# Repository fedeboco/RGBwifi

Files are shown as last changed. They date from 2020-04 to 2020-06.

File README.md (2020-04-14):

# ESP 8266 Wi-Fi RGB LED Strip Controller

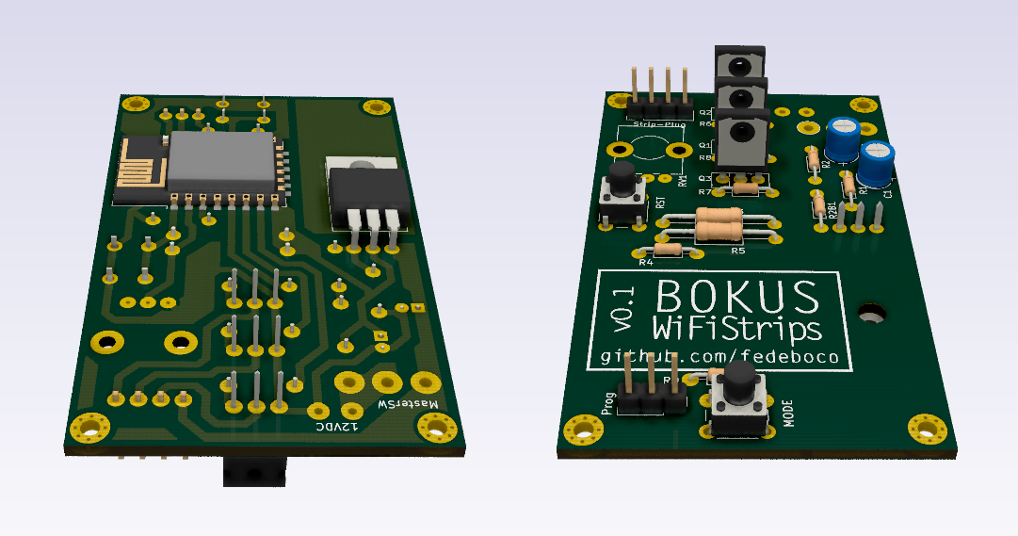
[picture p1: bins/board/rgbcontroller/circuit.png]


### Idea
- Local network WiFi server.
- Browser GUI for color selection.
- Analog on-board hue-color and brightness selection.
- Multiple board control (not implemented yet).

### WiFi Configuration Example

Connecting to an specific Wi-Fi network will be possible by fisrt connecting to an Access Point created by the ESP and sending the credentials using that network. The device stores the settings in EEPROM and restarts with the desired network configured.

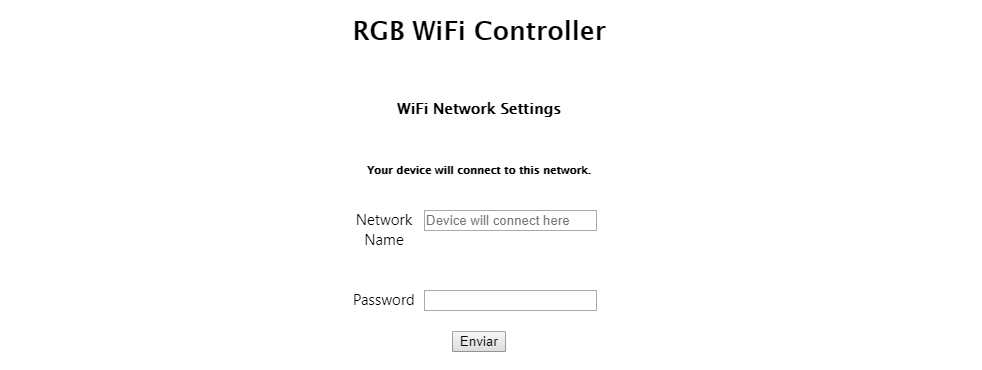
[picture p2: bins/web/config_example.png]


### Use Example

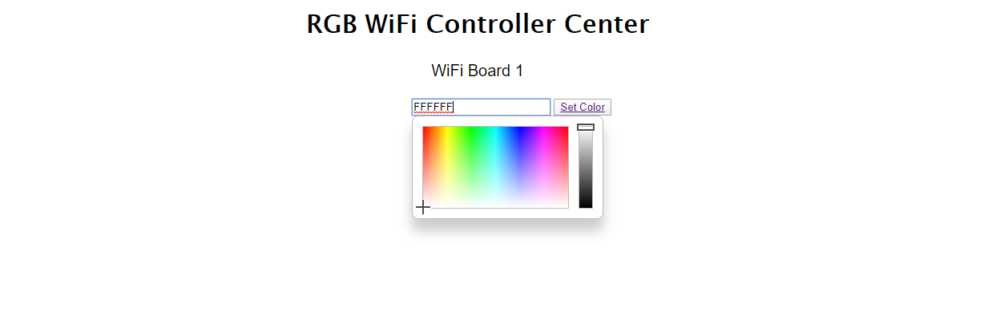
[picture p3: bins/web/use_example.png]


### Software and Dependencies
- Arduino IDE 1.8.3
- ESP8266 Board Driver by EP8266 Community. v2.5.0. https://github.com/esp8266/Arduino
- ESP8266 Web Server v1.0.0
- JavaScript Color Picker http://jscolor.com/

### Schematic

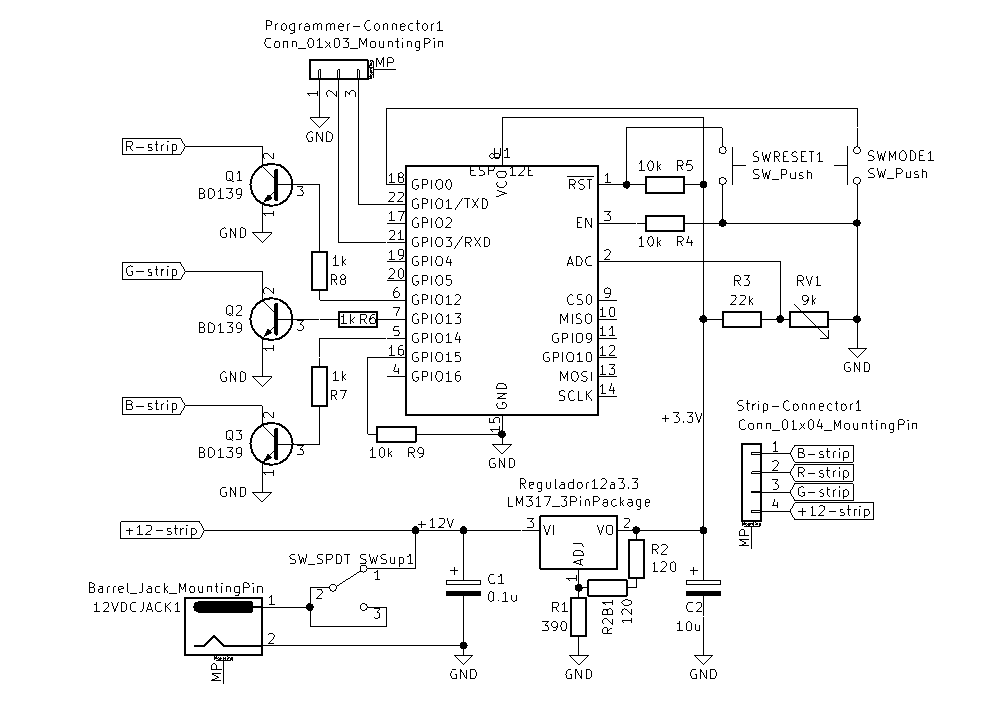
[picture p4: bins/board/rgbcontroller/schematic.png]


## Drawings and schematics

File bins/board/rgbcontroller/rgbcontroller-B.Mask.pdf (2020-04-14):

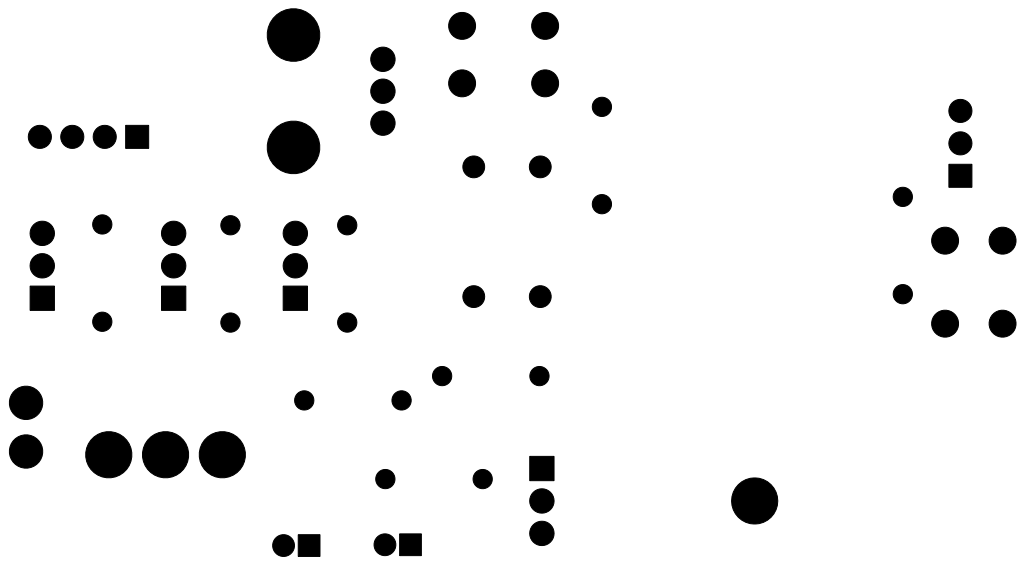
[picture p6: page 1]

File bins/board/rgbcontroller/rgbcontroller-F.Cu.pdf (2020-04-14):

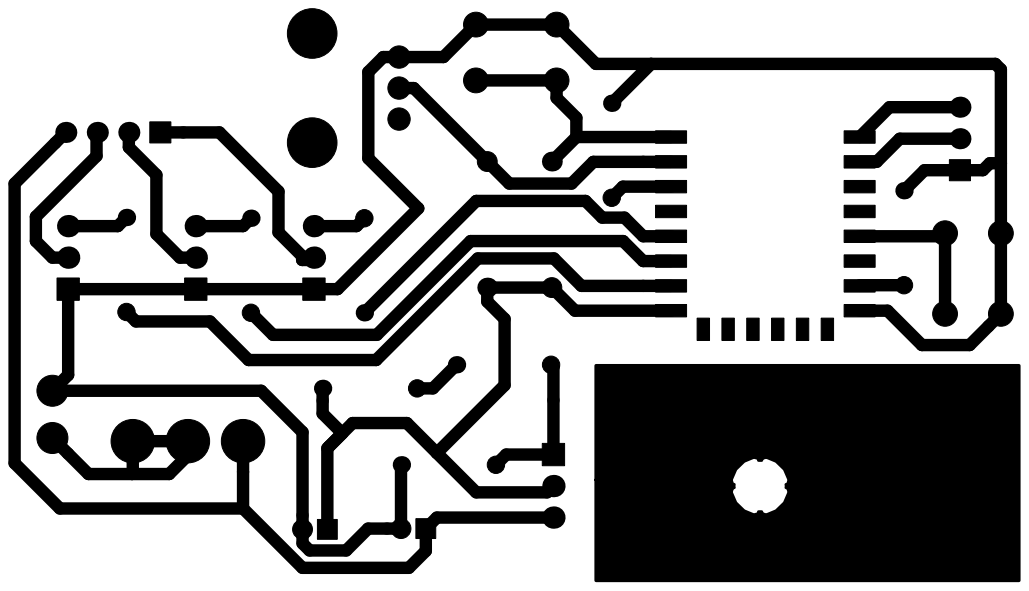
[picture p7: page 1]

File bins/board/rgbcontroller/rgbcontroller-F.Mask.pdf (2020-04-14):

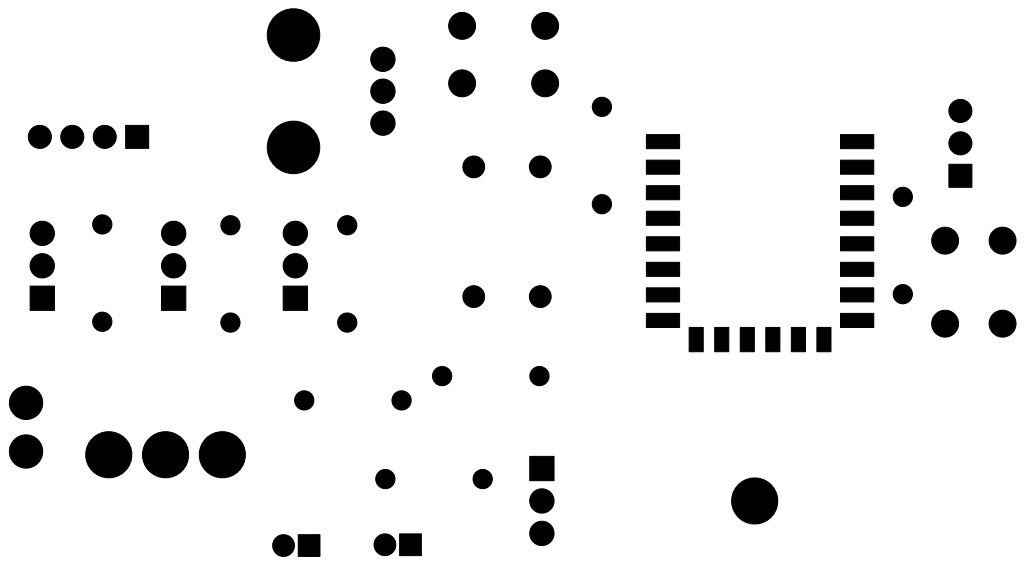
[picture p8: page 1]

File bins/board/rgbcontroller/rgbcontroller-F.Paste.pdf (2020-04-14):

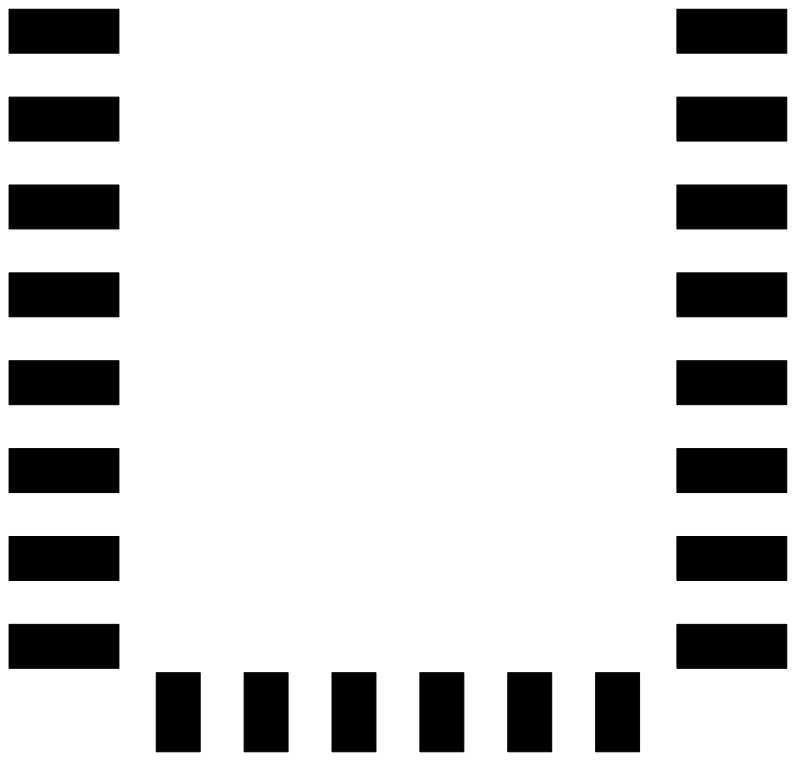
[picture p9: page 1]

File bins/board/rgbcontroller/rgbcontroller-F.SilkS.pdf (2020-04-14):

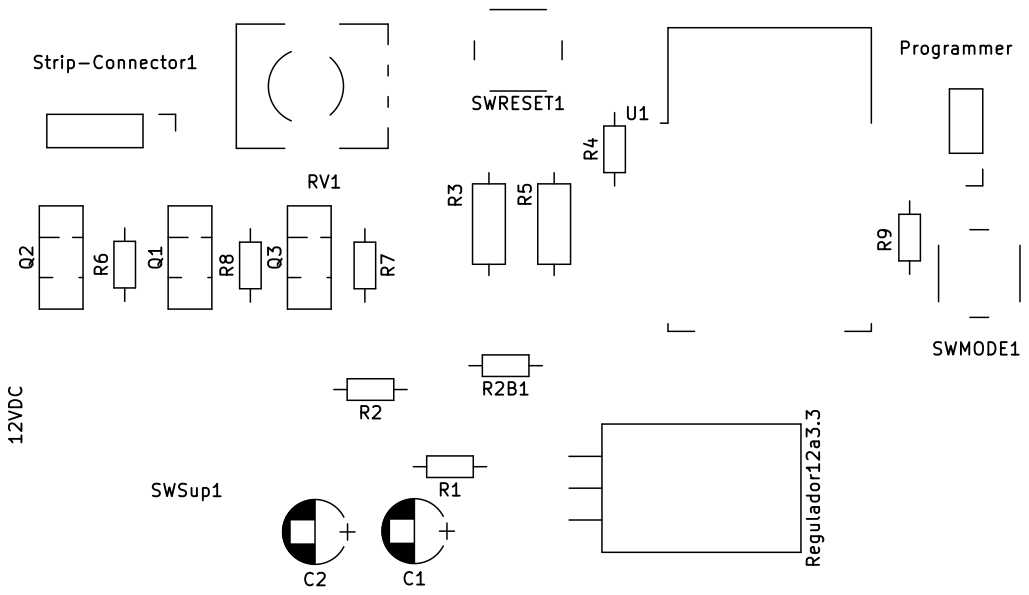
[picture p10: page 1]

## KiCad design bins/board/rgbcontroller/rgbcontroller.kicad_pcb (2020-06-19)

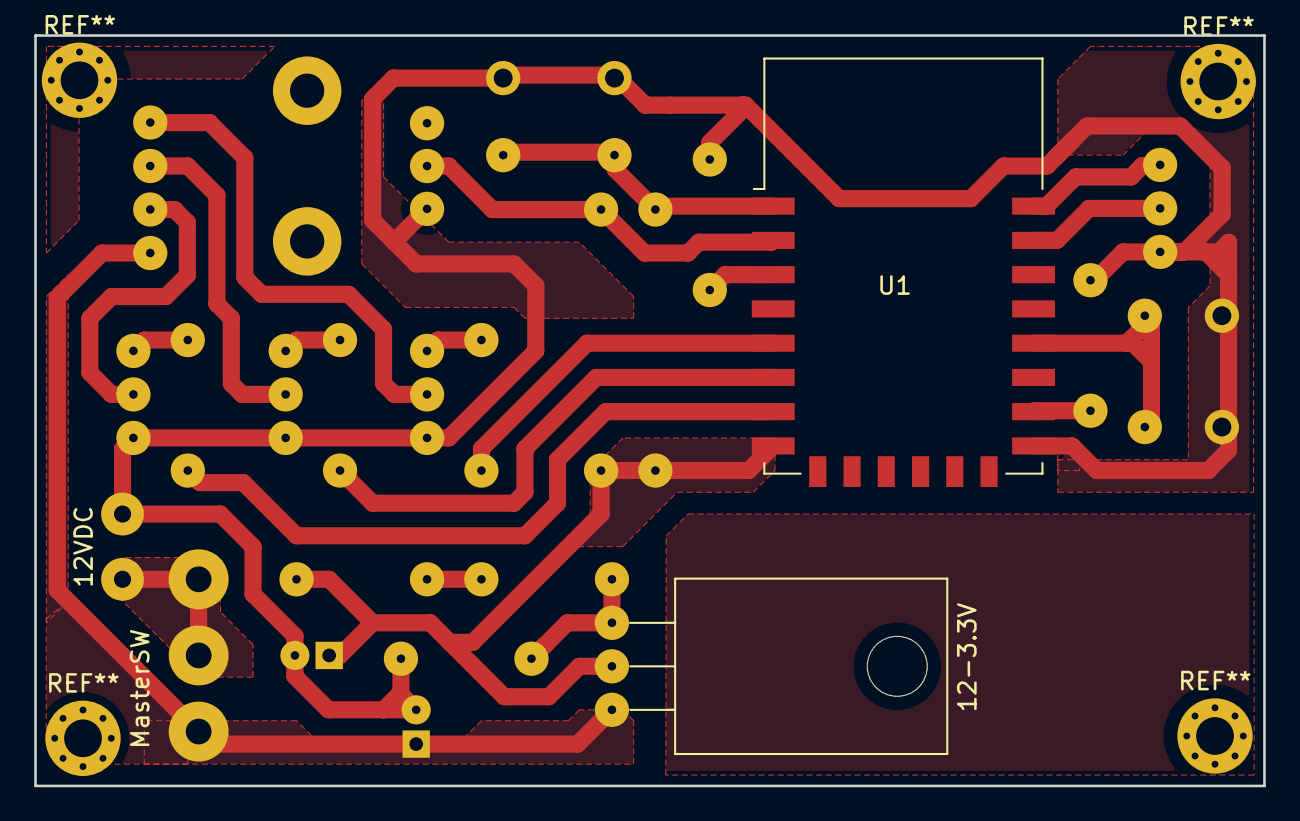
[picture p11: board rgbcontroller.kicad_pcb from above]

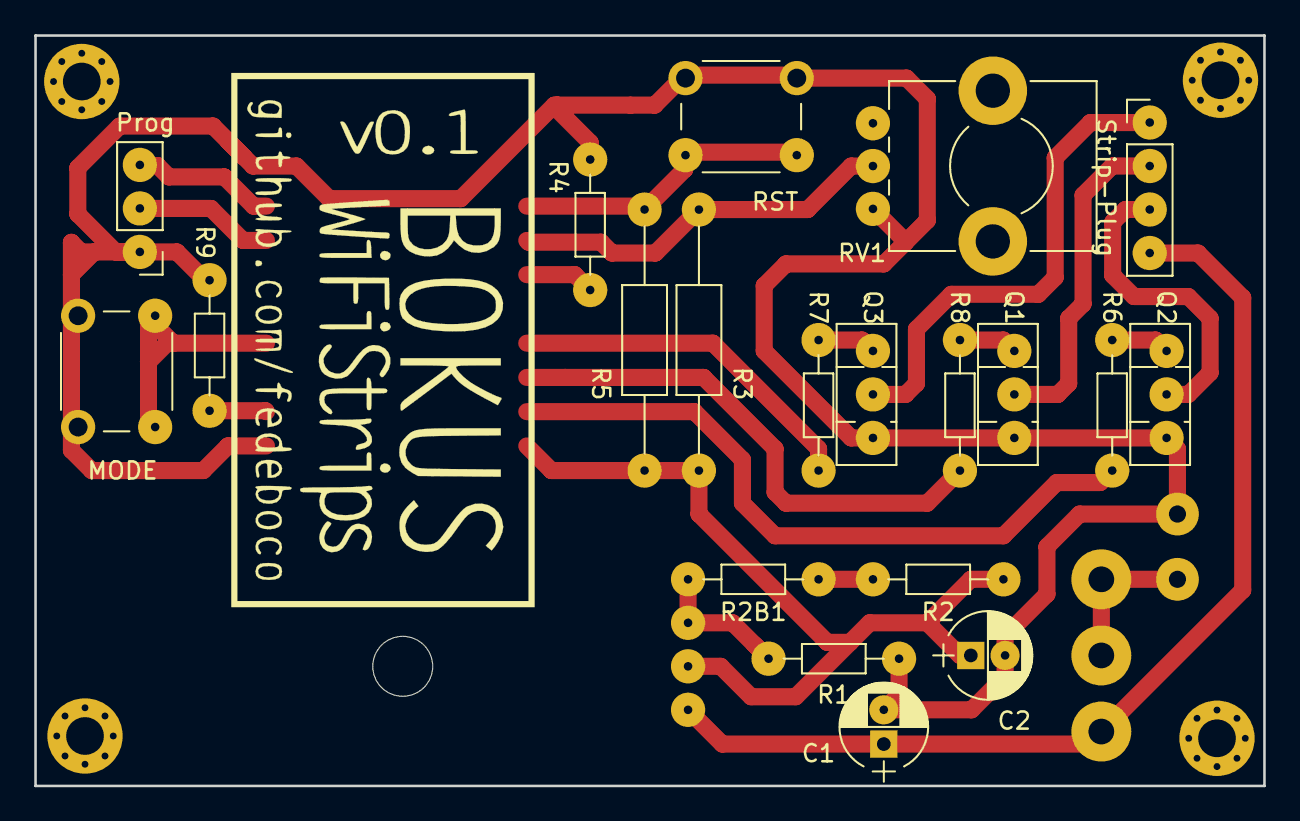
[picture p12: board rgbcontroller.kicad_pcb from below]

Board: 2 copper layers, 71.8 x 43.8 mm, 24 parts (20 on the bottom side), 22 nets.

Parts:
12-3.3V: LM317_3PinPackage; TO-220-3_Horizontal
12VDC: Barrel_Jack_MountingPin; SolderWirePad_2x_1mmDrill
C1: 0.1u; CP_Radial_D5.0mm_P2.00mm
C2: 10u; CP_Radial_D5.0mm_P2.00mm
MODE: SW_Push; SW_PUSH_6mm_h7.3mm
MasterSW: SW_SPDT; SolderWirePad_3x_1-5mmDrill
Prog: Conn_01x03_MountingPin; Pin_Header_Straight_1x03_Pitch2.54mm
Q1, Q2, Q3: BD139; TO-126_Vertical
R1: 390; R_Axial_DIN0204_L3.6mm_D1.6mm_P7.62mm_Horizontal
R2, R2B1: 120; R_Axial_DIN0204_L3.6mm_D1.6mm_P7.62mm_Horizontal
R3: 22k; R_Axial_DIN0207_L6.3mm_D2.5mm_P15.24mm_Horizontal
R4, R9: 10k; R_Axial_DIN0204_L3.6mm_D1.6mm_P7.62mm_Horizontal
R5: 10k; R_Axial_DIN0207_L6.3mm_D2.5mm_P15.24mm_Horizontal
R6, R7, R8: 1k; R_Axial_DIN0204_L3.6mm_D1.6mm_P7.62mm_Horizontal
RST: RST; SW_PUSH_6mm_h7.3mm
RV1: 9k; Potentiometer_Alps_RK09K_Horizontal
Strip-Plug: Conn_01x04_MountingPin; Pin_Header_Straight_1x04_Pitch2.54mm
U1: ESP-12E

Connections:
+12-strip: 12-3.3V.3, C1.1, MasterSW.1, Strip-Plug.4
/+3.3V: 12-3.3V.2, C2.1, R2.2, R3.2, R5.1, U1.8
B-strip: Q3.2, Strip-Plug.1
G-strip: Q2.2, Strip-Plug.3
GND: 12VDC.2, C1.2, C2.2, MODE.1, Prog.1, Q1.1, Q2.1, Q3.1, R1.2, R4.2, R9.2, RST.2, RV1.1, U1.15
unnamed: 12VDC.1, MasterSW.2, MasterSW.3
unnamed: Prog.2, U1.21
unnamed: Prog.3, U1.22
unnamed: Q1.3, R8.2
unnamed: Q2.3, R6.2
unnamed: Q3.3, R7.1
unnamed: 12-3.3V.1, R1.1, R2B1.1
unnamed: R2.1, R2B1.2
unnamed: R3.1, RV1.2, U1.2
unnamed: R4.1, U1.3
unnamed: R5.2, RST.1, U1.1
unnamed: R6.1, U1.7
unnamed: R7.2, U1.5
unnamed: R8.1, U1.6
unnamed: R9.1, U1.16
unnamed: MODE.2, U1.18
R-strip: Q1.2, Strip-Plug.2

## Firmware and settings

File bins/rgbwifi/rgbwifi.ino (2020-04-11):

#include "ESP8266WiFi.h"
#include "board.h"

const char* ssid = "Network-Name";
const char* password = "6#Z9K%L>e@7GdDtj";
board WiFiBoard(115200);

void setup() {
  WiFiBoard.serialWelcome();
  WiFiBoard.startStationMode();
  WiFiBoard.printNetworks();
  WiFiBoard.connect(ssid, password);
}

void loop() {
  WiFiBoard.updateMode();
  WiFiBoard.updateAnalogScale();
  WiFiBoard.updateManualControl();
  WiFiBoard.updateStrobe();
  WiFiBoard.updateBrightness();
  WiFiBoard.updateWiFiClient();
  WiFiBoard.updateColor();
  WiFiBoard.startAccessPointMode();
}

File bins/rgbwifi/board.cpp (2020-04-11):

#include "board.h"

board::board(int brate) : brate(brate), server(WiFiServer(80)), 
                          scaleValue(0), currentColor(color(0,0,0)),
                          scaleSum(0), RGB(strip(12,13,14)), mode(WIFI_MODE),
                          modeButton(0){
  Serial.begin(115200); //baud rate
  pinMode(2, OUTPUT);
  for(int i = 0; i < AVERAGE_LEN; i++) scaleValues.push(0);
}

void board::printNetworks() {
  // number of available networks
  int n = WiFi.scanNetworks();
  if (n == 0) 
    Serial.println("No networks available.");

  // prints number of networks
  Serial.print("Number of networks available: ");
  Serial.println(n);

  /* prints names (SSID), signal intensity (RSSI)
  and encryption type. */
  for (int i = 0; i < n; i++) {
    Serial.print(i + 1);
    Serial.print(") ");
    Serial.print(WiFi.SSID(i));
    Serial.print(" (RSSI: ");
    Serial.print(WiFi.RSSI(i));
    Serial.print("). ");
    printEncryptionType(WiFi.encryptionType(i));
    delay(50);
  }
}

void board::printEncryptionType(uint8_t enc) {
  if (enc == TKIP_WPA) Serial.println("WPA (TKIP)");
  else if (enc == CCMP_WPA) Serial.println("WPA (CCMP)");
  else if (enc == WEP) Serial.println("WEP");
  else if (enc == ENC_TYPE_NONE) Serial.println("Open network");
  else if (enc == AUTO) Serial.println("Auto");
  else Serial.println("Unknown encryption");
}

void board::connect(const char * ssid, const char * password) {
  
  WiFi.begin(loadCredential(0,128), loadCredential(128,256));
  waitForConnection();
  if (WiFi.status() == WL_CONNECTED) {
    Serial.print("\nConnected successfully to ");
    Serial.print(ssid);
    Serial.println(".");
    Serial.print("Device IP: ");
    Serial.println(WiFi.localIP());
    server.stop();
    server.begin();
  }
}

// waits for clients
WiFiClient board::listen() {
    return server.available();
}

void board::serialWelcome() {
  Serial.print("\n\n");
  Serial.println("--------------------------");
  Serial.println("RGB WiFi Strip Controller.");
  Serial.println("--------------------------");
}

void board::waitForConnection() {
  bool ledOn = true;
  uint8_t counter = 0;
  unsigned long timer = millis();

  digitalWrite(2, HIGH);
  while (WiFi.status() != WL_CONNECTED && millis() - timer < 7000) { 
    counter++;
    if (counter > 3) {
      Serial.print(".");
      if (ledOn) {
        ledOn = false;
        digitalWrite(2, LOW);
      } else {
        ledOn = true;
        digitalWrite(2, HIGH);
      }
      counter = 0;
    }
    delay(50);
  }
  digitalWrite(2, LOW);
}

void board::startAccessPointMode() {
  if (!modeButton.holded(3000)) return;

  server.stop();
  blinkStatusLed(10);
  netConfig conf;
  conf.updateCredentials();
  conf.serverStop();
  setup();
}

String board::loadCredential(int start, int end) {
  String buf = "";
  int i = start;
  char c = ' ';
  bool done = false;
  
  EEPROM.begin(512); 
  delay(10);
  while(i <= end && !done) {
    c = char(EEPROM.read(i));
    if (c == '\n') {
       done = true;
    } else {
       buf += c;
    }
    i++;  
  }
    
  Serial.print("LEO: ");
  Serial.println(buf);
  return buf;
}

void board::startStationMode() {
  WiFi.mode(WIFI_STA); //estacion
  WiFi.disconnect();
  delay(100);
}

void board::blinkStatusLed(uint8_t times) {
  bool ledOn = true;

  digitalWrite(2, HIGH);
  for (uint8_t i = 0; i < 2 * times; i++) {
      if (ledOn) {
        ledOn = false;
        digitalWrite(2, LOW);
      } else {
        ledOn = true;
        digitalWrite(2, HIGH);
      }
      delay(50);
  }
}

void board::updateManualControl() {
  if (mode != MANUAL_MODE) return;
  currentColor.rainbow(scaleSum / AVERAGE_LEN);
}

void board::updateStrobe() {
  if (mode != STROBE_MODE) return;
  RGB.strobe(currentColor, strobeIndex);
}

void board::updateBrightness() {
  if (mode == MANUAL_MODE) return;
  RGB.setBrightness(scaleSum / AVERAGE_LEN);
}

void board::updateColor() {
  if (mode == WIFI_MODE) {
     RGB.setColor(WiFiCurrentColor);
  } else {
     RGB.setColor(currentColor);
  }
}

void board::updateAnalogScale() {
  scaleSum += scaleValues.back();
  scaleSum -= scaleValues.front();
  scaleValues.push(analogRead(A0) / 1023.0 / 0.88);
  scaleValues.pop();
}

void board::updateMode() {
  if (modeButton.isPressed()) {
    mode = (boardMode_t) (mode + 1);
    if (mode == DEFAULT_MODE)
      mode = (boardMode_t) 0;
    RGB.flash(FLASH_DELAY, color(WHITE), FLASH_TIMES);
  }
}
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

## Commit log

2020-04-04 Improved stability and color intensity
    [rgbwifi.ino, strip.cpp]
2020-04-10 Button hold check, Network Config Class
2020-06-18 PCB adjustments
    [rgbcontroller.kicad_pcb]
2020-06-19 Minor screws adjustments
    [rgbcontroller.kicad_pcb]
